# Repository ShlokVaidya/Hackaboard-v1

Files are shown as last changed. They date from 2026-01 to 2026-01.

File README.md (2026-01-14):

# 🎹 Hackaboard - The Hackaboard Keyboard

Welcome to **Hackaboard**, a beautifully crafted **63% mechanical keyboard** that combines aesthetics, functionality, and a touch of personality. A versatile keyboard designed to elevate your typing experience.

---

## ✨ What is Hackaboard?

Hackaboard is a custom mechanical keyboard featuring a 63% layout with modern conveniences like an **OLED display**, **rotary encoder**, and **full programmability**. Whether you're a developer, writer, designer, or gamer, this keyboard adapts to your workflow with support for multiple keymap configurations.

---

## 📸 Gallery

Take a look at the Hackaboard in all its glory:

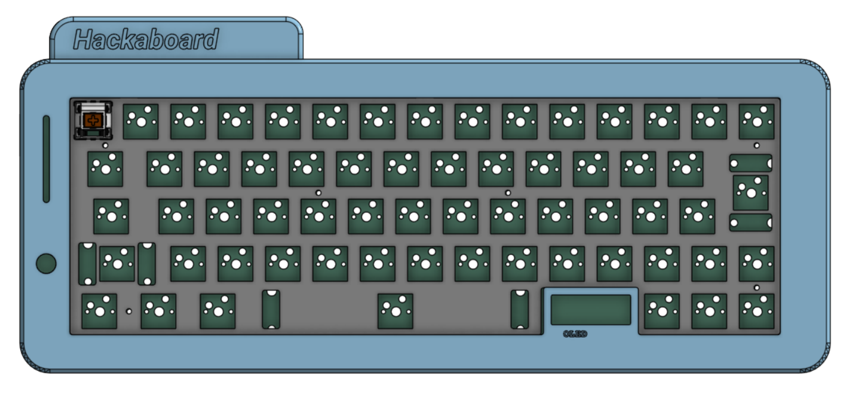
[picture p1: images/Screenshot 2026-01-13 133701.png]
Hackaboard Overview 1


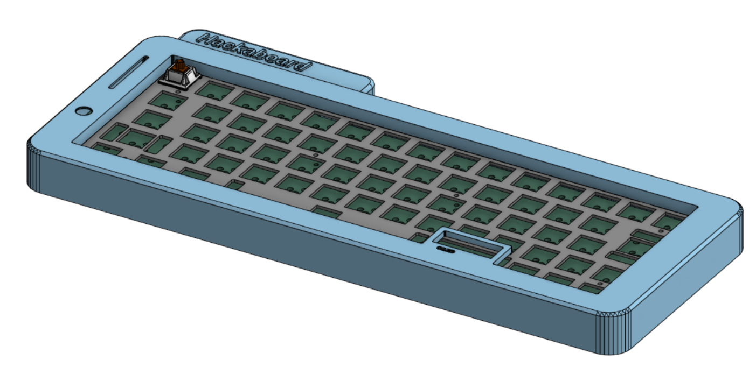
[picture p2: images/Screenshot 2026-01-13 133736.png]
Hackaboard Overview 2


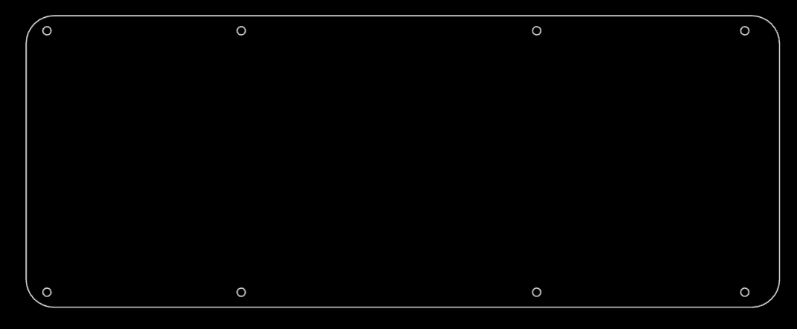
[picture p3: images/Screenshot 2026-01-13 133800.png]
Hackaboard Overview 3


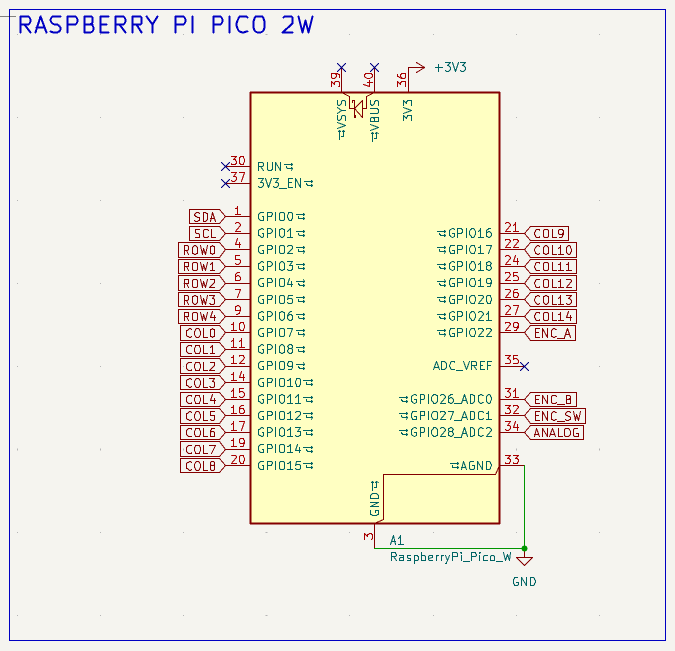
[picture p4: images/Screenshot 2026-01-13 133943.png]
Hackaboard Overview 4


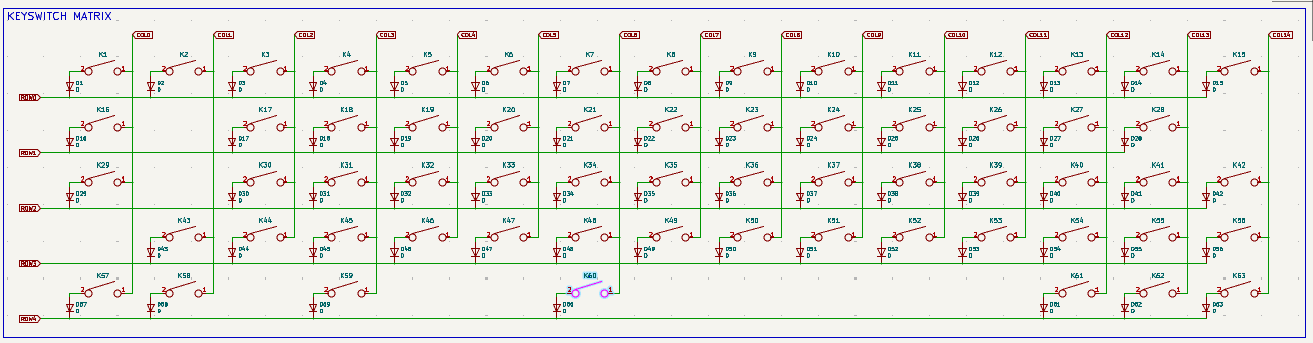
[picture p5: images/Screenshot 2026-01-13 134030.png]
Hackaboard Overview 5


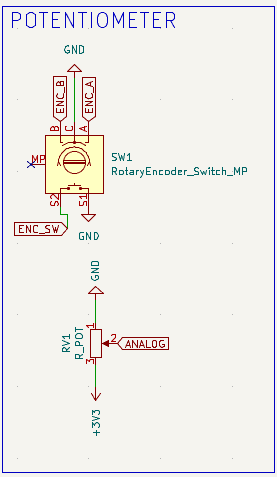
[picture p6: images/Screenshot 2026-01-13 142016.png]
Hackaboard Overview 6


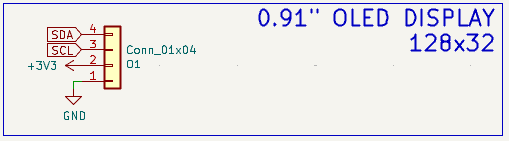
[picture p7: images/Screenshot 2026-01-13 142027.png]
Hackaboard Overview 7


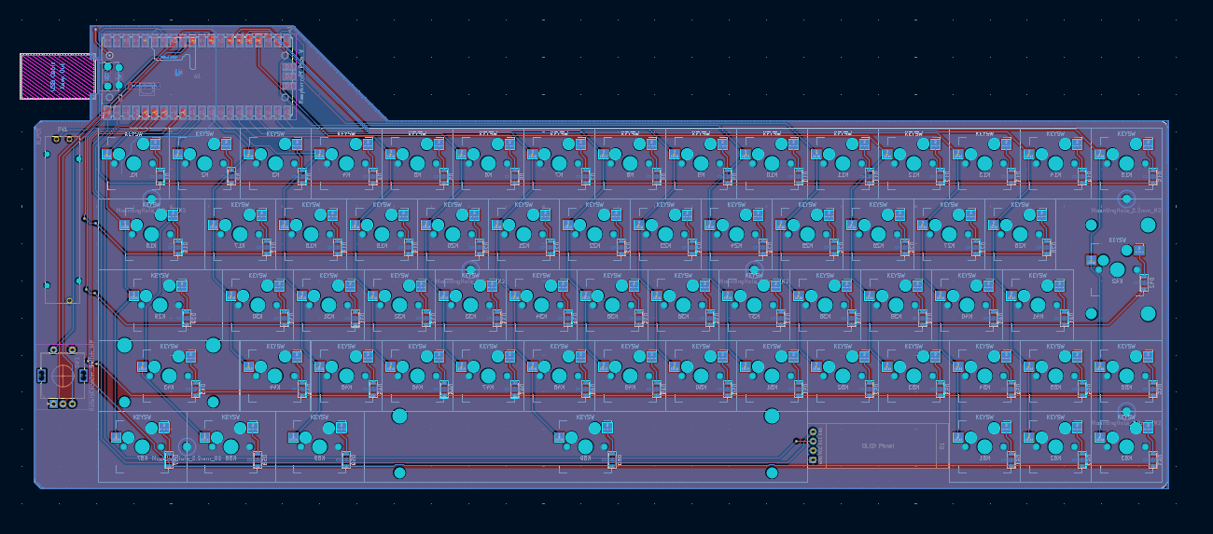
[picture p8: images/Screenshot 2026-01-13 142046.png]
Hackaboard Overview 8


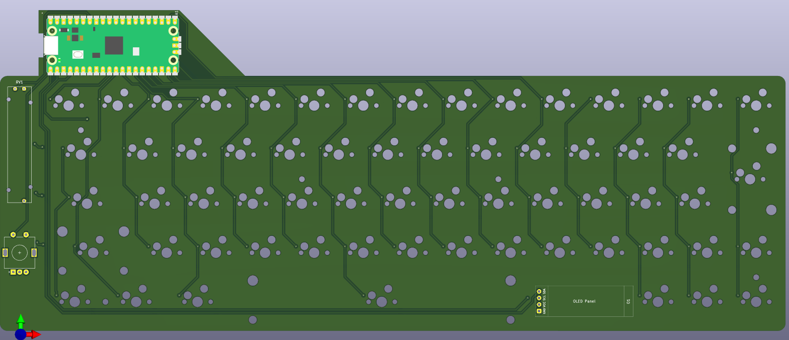
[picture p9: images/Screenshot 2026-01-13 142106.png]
Hackaboard Overview 9


---

## 🎯 Key Features

### Hardware Specs
- **Layout:** 63% compact form factor (63 keys)
- **Microcontroller:** Raspberry Pi Pico 2W (RP2350, supports QMK firmware)
- **Matrix:** 5 rows × 15 columns (COL2ROW configuration)
- **Switch Type:** Cherry MX PCB hotswap compatible
- **Display:** SSD1306 0.91" OLED (128x32 pixels)
- **Input:** EC11 Rotary Encoder with knob support
- **Debounce:** 5ms for reliable key registration

### Software Capabilities
- **Firmware:** QMK-compatible with custom configuration
- **Encoder:** Customizable rotary encoder with 4-level resolution
- **MIDI Support:** Full MIDI protocol implementation for music applications
- **Macros:** Built-in email address macro with right shift + 2
- **Keymaps:** Multiple pre-configured layouts (see below)

Please read [the Journal](./hackaboard-journal.md)
---

## ⌨️ Keymap Configurations

Hackaboard comes with **4 pre-built keymaps** to suit different typing styles and use cases:

### 1. **Default Keymap**
The standard ANSI layout – perfect for everyday typing and programming.

### 2. **Photographer Keymap**
Optimized for photo editing workflows with custom shortcuts and macro assignments.

### 3. **Writer Keymap**
Specialized layout for content creators with quick-access keys for common writing functions.

### 4. **VIA-Compatible Keymap**
Full support for the VIA configurator, allowing you to reprogram your keyboard without touching code.

---

# BOM table

Category | Item | Website | Cost (INR) | Cost (USD)
-- | -- | -- | -- | --
MCU | Raspberry Pi Pico 2 | Robu.in | ₹544 | $6
Diodes | 1N4148 SOD-123 (×63) | Robu.in | ₹36 | $0.4
Shipping (MCU + diodes) | — | Robu.in | ₹49 | $0.54
Subtotal (MCU + diodes) |   |   | ₹630 | $7
Conversion fee (3%) |   |   | ₹650 | $7.22
MCU + Diodes Total |   |   | ₹650 | $7.22
PCB | 2-layer PCB (base settings, incl. GST + shipping) | LionCircuits | ₹5,281 | $58.68
Conversion fee (3%) |   |   | ₹159 | $1.77
PCB Total |   |   | ₹5,440 | $60.45
Switches + Stabilizers + Hotswap sockets | (x45 + x10 pack) | StacksKB | ₹3,604 | $40.04
Conversion fee (3%) |   |   | ₹108 | $1.20
Switches Total |   |   | ₹3,712 | $41.24
Keycaps | Full keycap set | CuriosityCaps | ₹1,999 | $22.21
Conversion fee (3%) |   |   | ₹59 | $0.66
Keycaps Total |   |   | ₹2,058 | $22.87
Non-metal Plate | Plate | robu.in | Rs 330 | 3.6 USD
Screws | | onlyscrews.in | Rs 400 | 4.5 USD
0.91" OLED | | I have
Potentiometer | | I have

And i need 3d printing from #printing-legion so that's Rs 820 or **9 USD**.

## Total
Currency | Total
-- | --
INR | ₹13,400
USD | $147.25 

---

## 🛠️ File Structure

```
Hackaboard-v1/
├── keyboards/hackaboard/         # Main keyboard configuration
│   ├── config.h                  # Hardware configuration
│   ├── info.json                 # Layout and metadata
│   ├── hackaboard.c              # Firmware logic
│   ├── hackaboard.h              # Firmware headers
│   ├── rules.mk                  # Build rules
│   └── keymaps/                  # Keymap definitions
│       ├── default/              # Default layout
│       ├── photographer/         # Photo editing optimized
│       ├── writer/               # Content creation optimized
│       └── via/                  # VIA configurator support
├── PCB/                          # KiCAD PCB design files
│   ├── hackaboard.kicad_sch      # Schematic
│   ├── hackaboard.kicad_pcb      # PCB layout
│   └── production/               # Manufacturing files (BOM, positions)
├── CAD/                          # 3D models and mechanical design
│   ├── case/                     # Keyboard case designs
│   └── plate/                    # Stabilizer plate designs
└── images/                       # Product photography
```

---

## 🚀 Getting Started

### Prerequisites
- QMK Firmware environment set up ([QMK Docs](https://docs.qmk.fm/))
- Python 3.6+ and pip
- ARM GCC toolchain (for RP2350)

### Building the Firmware

1. **Clone the QMK repository** and copy the Hackaboard firmware:
   ```bash
   git clone https://github.com/qmk/qmk_firmware.git
   cp -r keyboards/hackaboard/ qmk_firmware/keyboards/
   ```

2. **Build your preferred keymap:**
   ```bash
   qmk compile -kb hackaboard -km default
   ```

3. **Flash to your keyboard:**
   ```bash
   qmk flash -kb hackaboard -km default
   ```

### VIA Support
If you prefer a graphical interface, use the **VIA configurator**:
1. Download [VIA](https://www.caniusevia.com/)
2. Load the VIA keymap onto your Hackaboard
3. Customize in real-time without reflashing

---

## 🎨 Customization

### Rotary Encoder
The EC11 encoder on Hackaboard can be customized for:
- Volume control
- Scroll wheel simulation
- Layer switching
- Application shortcuts

### OLED Display
The tiny 0.91" OLED shows:
- Current layer information
- Keyboard status
- Custom animations
- Typing statistics

### Email Macro
Quickly insert your email address:
- **Key Combo:** Right Shift + 2
- **Default:** `shlokvaidya.in@gmail.com.com` (customize in `config.h`)

---

## 🔧 Advanced Features

### MIDI Mode
Hackaboard supports MIDI communication for:
- Virtual instrument control
- DAW integration
- Music production workflows

### Debounce Tuning
Adjust key sensitivity without reflashing:
- Current debounce: 5ms
- Modify `DEBOUNCE` in `config.h` if needed

### Custom Firmware Logic
Edit `hackaboard.c` and `hackaboard.h` to add:
- Complex macros
- Display animations
- Sensor integrations
- Hardware customizations

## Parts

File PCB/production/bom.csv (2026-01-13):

Designator | Footprint | Quantity | Value | LCSC Part #
A1 | RaspberryPi_Pico_SMD_HandSolder | 1 | RaspberryPi_Pico_W
D1, D10, D11, D12, D13, D14, D15, D16, D17, D18, D19, D2, D20, D21, D22, D23, D24, D25, D26, D27, D28, D29, D3, D30, D31, D32, D33, D34, D35, D36, D37, D38, D39, D4, D40, D41, D42, D43, D44, D45, D46, D47, D48, D49, D5, D50, D51, D52, D53, D54, D55, D56, D57, D58, D59, D6, D60, D61, D62, D63, D7, D8, D9 | D_SOD-123 | 63 | D
K1, K10, K11, K12, K13, K14, K15, K17, K18, K19, K2, K20, K21, K22, K23, K24, K25, K26, K27, K28, K3, K30, K31, K32, K33, K34, K35, K36, K37, K38, K39, K4, K40, K41, K44, K45, K46, K47, K48, K49, K5, K50, K51, K52, K53, K54, K55, K56, K6, K61, K62, K63, K7, K8, K9 | MXOnly-1U-Hotswap | 55 | KEYSW
K16 | MXOnly-1.5U-Hotswap | 1 | KEYSW
K29 | MXOnly-1.75U-Hotswap | 1 | KEYSW
K42 | MXOnly-ISO-Hotswap | 1 | KEYSW
K43 | MXOnly-2U-Hotswap-ReversedStabilizers | 1 | KEYSW
K57, K58, K59 | MXOnly-1.25U-Hotswap | 3 | KEYSW
K60 | MXOnly-6.25U-Hotswap-ReversedStabilizers | 1 | KEYSW
O1 | SSD1306-0.91-OLED-4pin-128x32 | 1 | Conn_01x04
RV1 | potentiometer_slider_45mm | 1 | R_POT
SW1 | RotaryEncoder_Alps_EC11E-Switch_Vertical_H20mm | 1 | RotaryEncoder_Switch_MP

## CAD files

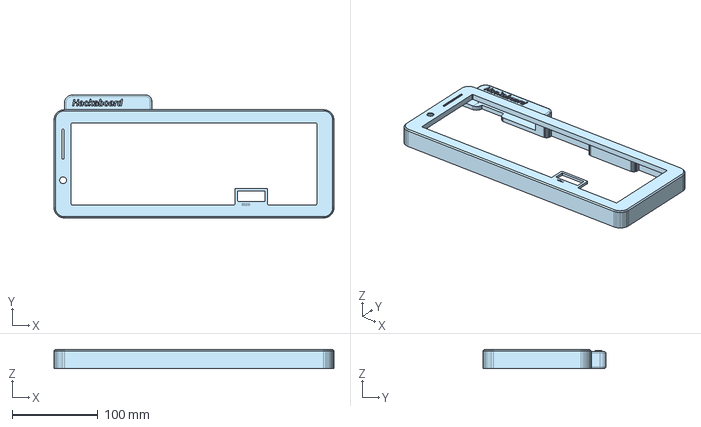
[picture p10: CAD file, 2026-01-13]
CAD/case/case.step
325.8 x 143.0 x 22.4 mm

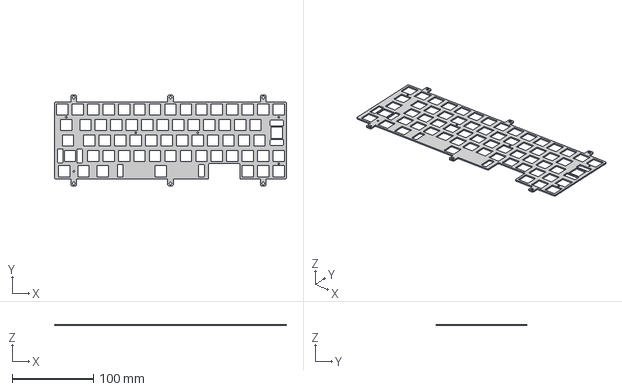
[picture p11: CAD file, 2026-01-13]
CAD/plate/Plate.step
285.7 x 111.8 x 1.50 mm

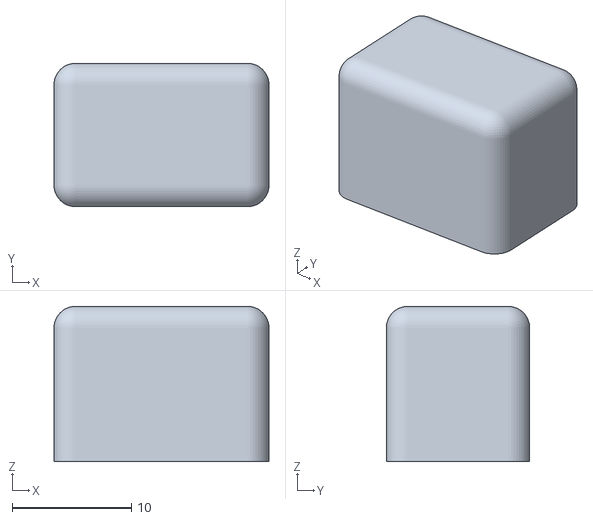
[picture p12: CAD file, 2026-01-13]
CAD/slider cap/slide cap.stl
18.0 x 12.0 x 13.0

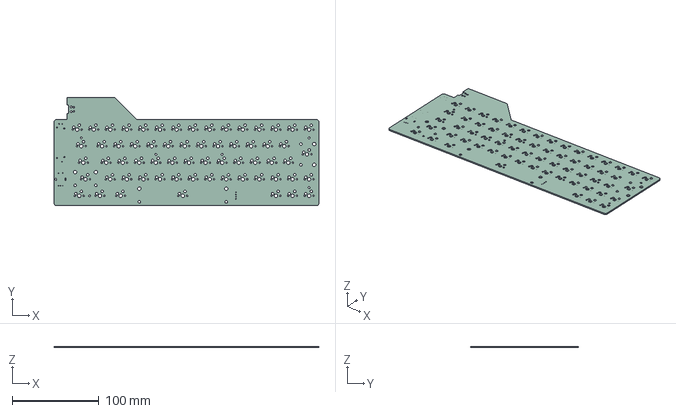
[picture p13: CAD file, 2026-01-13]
CAD/case/hackaboard.step
304.7 x 124.5 x 1.51 mm

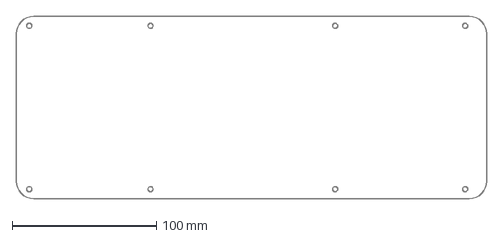
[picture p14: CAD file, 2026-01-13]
CAD/case/buttom_plate.dxf
325.7 x 126.0 mm

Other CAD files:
CAD/plate/plate.dxf

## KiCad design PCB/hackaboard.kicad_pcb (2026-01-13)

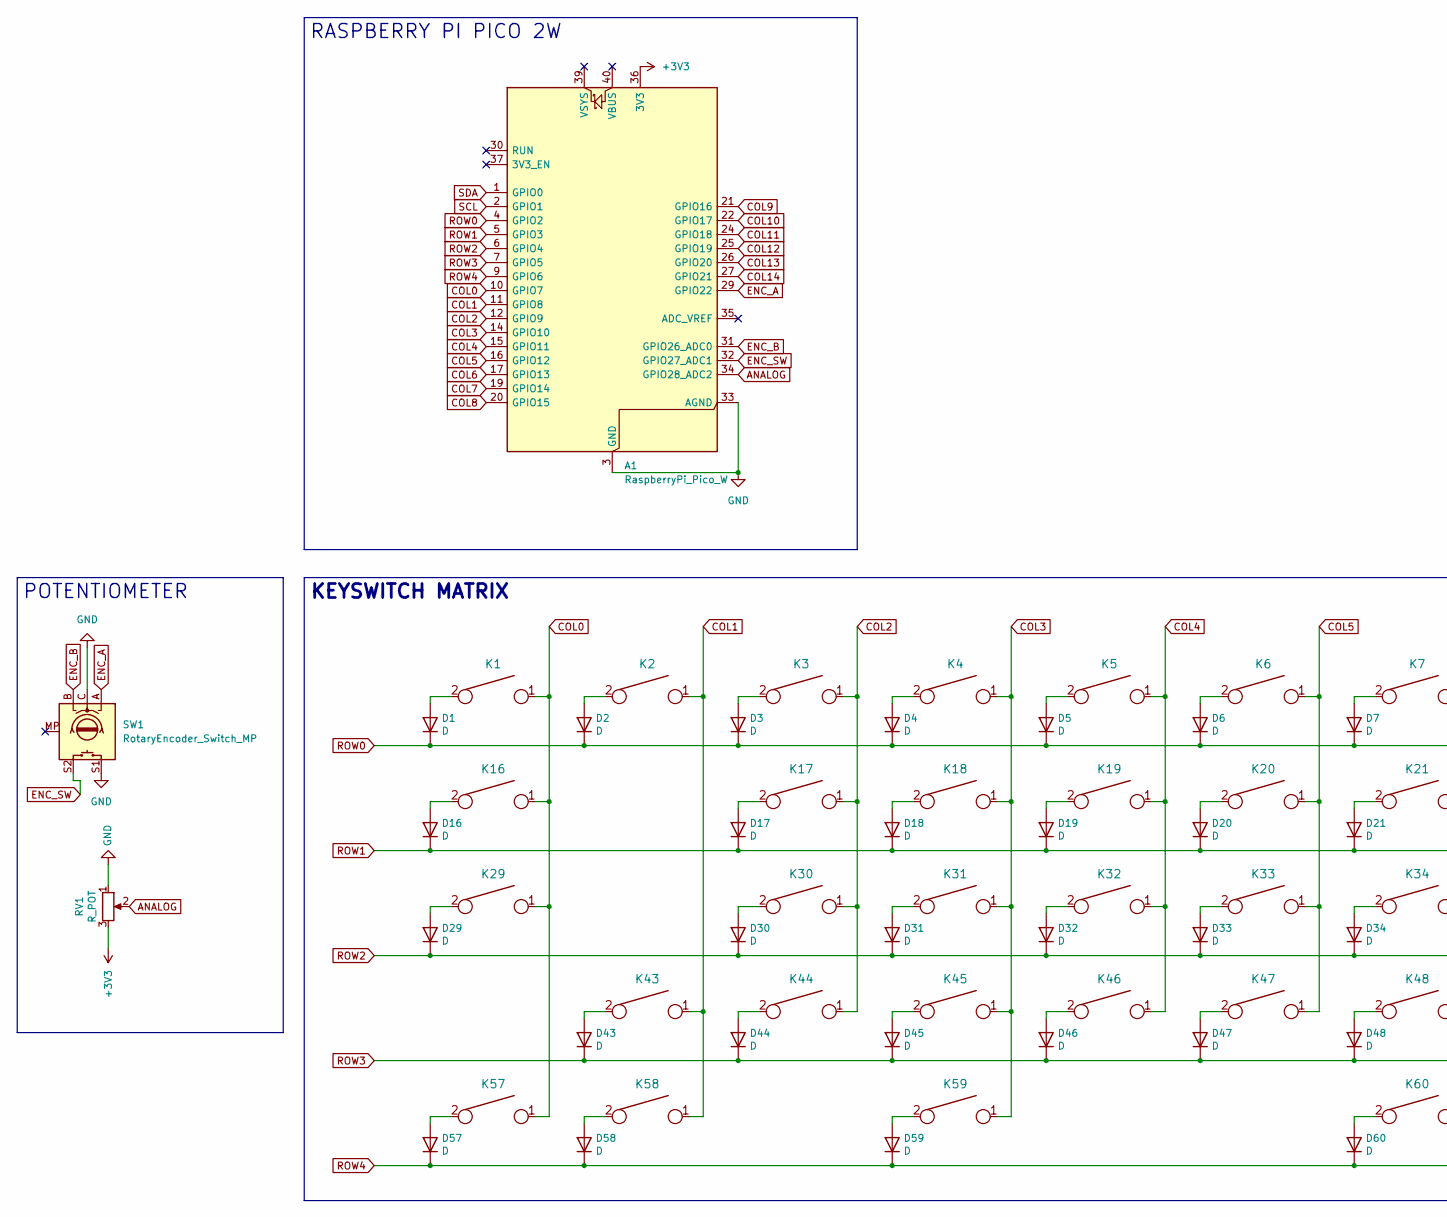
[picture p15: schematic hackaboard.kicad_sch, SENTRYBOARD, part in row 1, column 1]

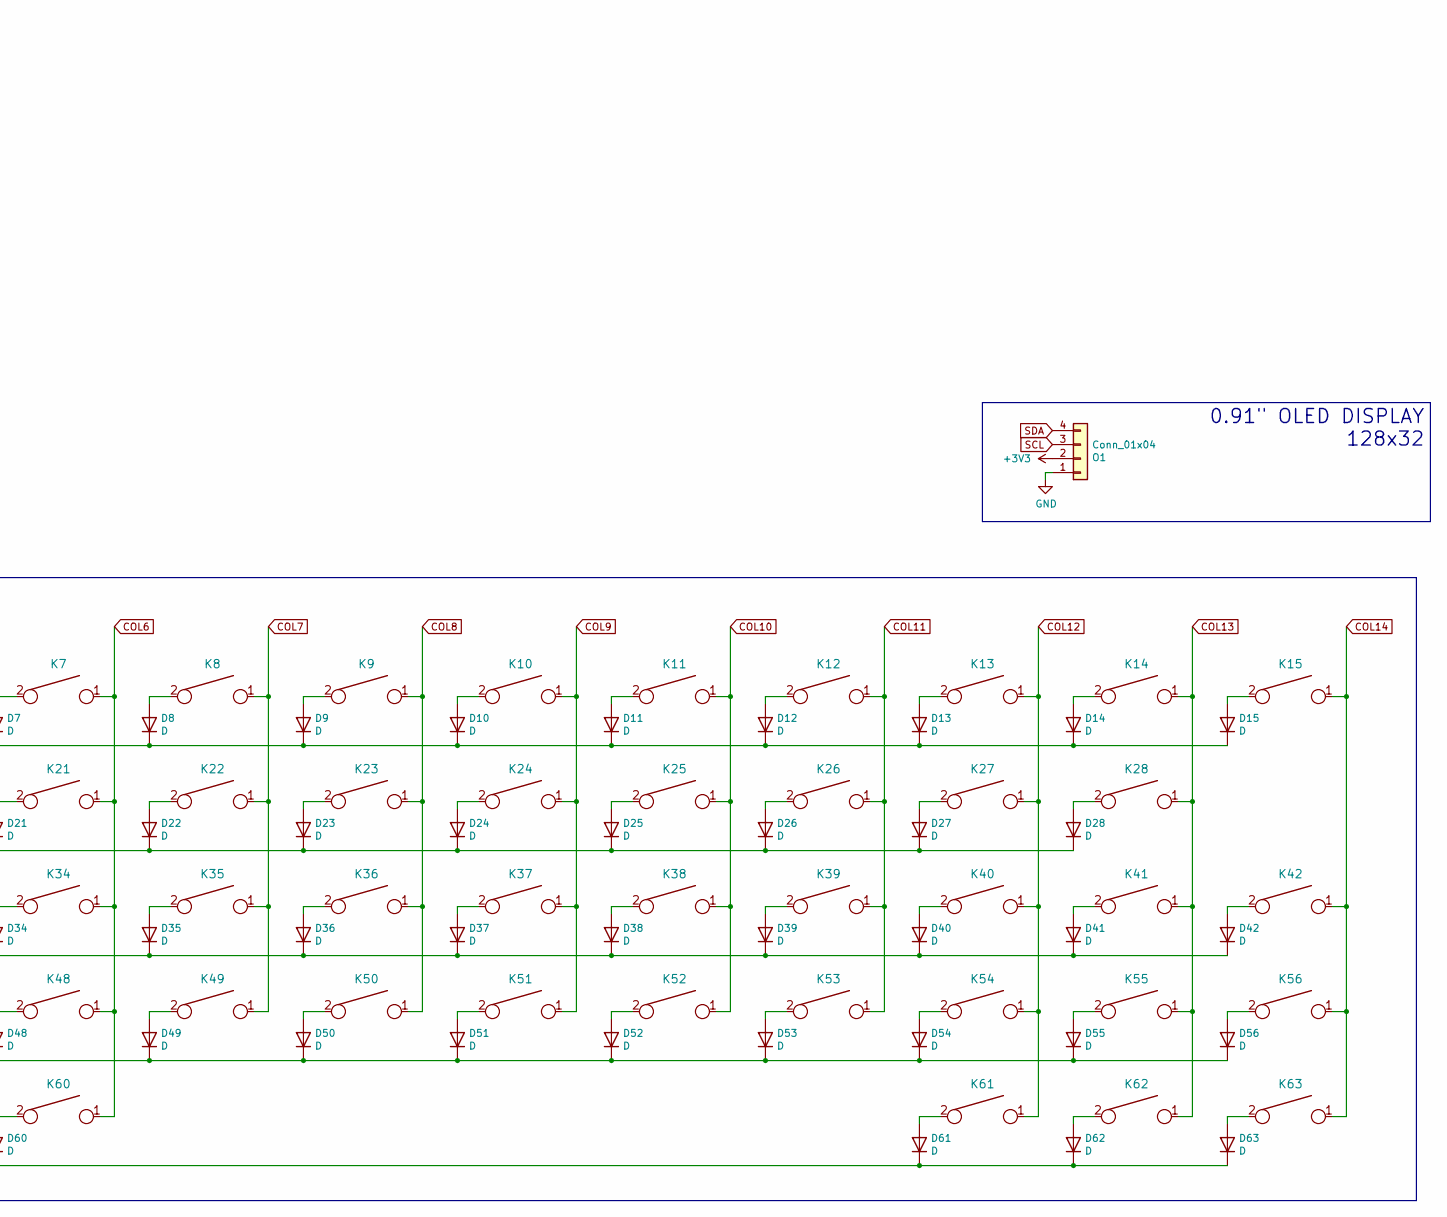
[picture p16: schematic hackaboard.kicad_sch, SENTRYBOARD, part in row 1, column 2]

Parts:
A1: RaspberryPi_Pico_W; RaspberryPi_Pico_SMD_HandSolder
D1, D2, D3, D4, D5, D6, D7, D8, D9, D10, D11, D12, D13, D14, D15, D16, D17, D18, D19, D20, D21, D22, D23, D24, D25, D26, D27, D28, D29, D30, D31, D32, D33, D34, D35, D36, D37, D38, D39, D40, D41, D42, D43, D44, D45, D46, D47, D48, D49, D50, D51, D52, D53, D54, D55, D56, D57, D58, D59, D60, D61, D62, D63: D; D_SOD-123
K1, K2, K3, K4, K5, K6, K7, K8, K9, K10, K11, K12, K13, K14, K15, K17, K18, K19, K20, K21, K22, K23, K24, K25, K26, K27, K28, K30, K31, K32, K33, K34, K35, K36, K37, K38, K39, K40, K41, K44, K45, K46, K47, K48, K49, K50, K51, K52, K53, K54, K55, K56, K61, K62, K63: KEYSW; MXOnly-1U-Hotswap
K16: KEYSW; MXOnly-1.5U-Hotswap
K29: KEYSW; MXOnly-1.75U-Hotswap
K42: KEYSW; MXOnly-ISO-Hotswap
K43: KEYSW; MXOnly-2U-Hotswap-ReversedStabilizers
K57, K58, K59: KEYSW; MXOnly-1.25U-Hotswap
K60: KEYSW; MXOnly-6.25U-Hotswap-ReversedStabilizers
O1: Conn_01x04; SSD1306-0.91-OLED-4pin-128x32
RV1: R_POT; potentiometer_slider_45mm
SW1: RotaryEncoder_Switch_MP; RotaryEncoder_Alps_EC11E-Switch_Vertical_H20mm

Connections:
+3V3: A1.36 (3V3), O1.2, RV1.3
ANALOG: A1.34 (GPIO28_ADC2), RV1.2
COL0: A1.10 (GPIO7), K1.1, K16.1, K29.1, K57.1
COL1: A1.11 (GPIO8), K2.1, K43.1, K58.1
COL2: A1.12 (GPIO9), K3.1, K17.1, K30.1, K44.1
COL3: A1.14 (GPIO10), K4.1, K18.1, K31.1, K45.1, K59.1
COL4: A1.15 (GPIO11), K5.1, K19.1, K32.1, K46.1
COL5: A1.16 (GPIO12), K6.1, K20.1, K33.1, K47.1
COL6: A1.17 (GPIO13), K7.1, K21.1, K34.1, K48.1, K60.1
COL7: A1.19 (GPIO14), K8.1, K22.1, K35.1, K49.1
COL8: A1.20 (GPIO15), K9.1, K23.1, K36.1, K50.1
COL9: A1.21 (GPIO16), K10.1, K24.1, K37.1, K51.1
COL10: A1.22 (GPIO17), K11.1, K25.1, K38.1, K52.1
COL11: A1.24 (GPIO18), K12.1, K26.1, K39.1, K53.1
COL12: A1.25 (GPIO19), K13.1, K27.1, K40.1, K54.1, K61.1
COL13: A1.26 (GPIO20), K14.1, K28.1, K41.1, K55.1, K62.1
COL14: A1.27 (GPIO21), K15.1, K42.1, K56.1, K63.1
ENC_A: A1.29 (GPIO22), SW1.A
ENC_B: A1.31 (GPIO26_ADC0), SW1.B
ENC_SW: A1.32 (GPIO27_ADC1), SW1.S2
GND: A1.3 (GND), A1.8 (GND), A1.13 (GND), A1.18 (GND), A1.23 (GND), A1.28 (GND), A1.33 (AGND), A1.38 (GND), O1.1, RV1.1, SW1.C, SW1.S1
unnamed: D1.2 (A), K1.2
unnamed: D2.2 (A), K2.2
unnamed: D3.2 (A), K3.2
unnamed: D4.2 (A), K4.2
unnamed: D5.2 (A), K5.2
unnamed: D6.2 (A), K6.2
unnamed: D7.2 (A), K7.2
unnamed: D8.2 (A), K8.2
unnamed: D9.2 (A), K9.2
unnamed: D10.2 (A), K10.2
unnamed: D11.2 (A), K11.2
unnamed: D12.2 (A), K12.2
unnamed: D13.2 (A), K13.2
unnamed: D14.2 (A), K14.2
unnamed: D15.2 (A), K15.2
unnamed: D16.2 (A), K16.2
unnamed: D17.2 (A), K17.2
unnamed: D18.2 (A), K18.2
unnamed: D19.2 (A), K19.2
unnamed: D20.2 (A), K20.2
unnamed: D21.2 (A), K21.2
unnamed: D22.2 (A), K22.2
unnamed: D23.2 (A), K23.2
unnamed: D24.2 (A), K24.2
unnamed: D25.2 (A), K25.2
unnamed: D26.2 (A), K26.2
unnamed: D27.2 (A), K27.2
unnamed: D28.2 (A), K28.2
unnamed: D29.2 (A), K29.2
unnamed: D30.2 (A), K30.2
unnamed: D31.2 (A), K31.2
unnamed: D32.2 (A), K32.2
unnamed: D33.2 (A), K33.2
unnamed: D34.2 (A), K34.2
unnamed: D35.2 (A), K35.2
unnamed: D36.2 (A), K36.2
unnamed: D37.2 (A), K37.2
unnamed: D38.2 (A), K38.2
unnamed: D39.2 (A), K39.2
unnamed: D40.2 (A), K40.2
unnamed: D41.2 (A), K41.2
unnamed: D42.2 (A), K42.2
unnamed: D43.2 (A), K43.2
unnamed: D44.2 (A), K44.2
unnamed: D45.2 (A), K45.2
unnamed: D46.2 (A), K46.2
unnamed: D47.2 (A), K47.2
unnamed: D48.2 (A), K48.2
unnamed: D49.2 (A), K49.2
unnamed: D50.2 (A), K50.2
unnamed: D51.2 (A), K51.2
unnamed: D52.2 (A), K52.2
unnamed: D53.2 (A), K53.2
unnamed: D54.2 (A), K54.2
unnamed: D55.2 (A), K55.2
unnamed: D56.2 (A), K56.2
unnamed: D57.2 (A), K57.2
unnamed: D58.2 (A), K58.2
unnamed: D59.2 (A), K59.2
unnamed: D60.2 (A), K60.2
unnamed: D61.2 (A), K61.2
unnamed: D62.2 (A), K62.2
unnamed: D63.2 (A), K63.2
ROW0: A1.4 (GPIO2), D1.1 (K), D2.1 (K), D3.1 (K), D4.1 (K), D5.1 (K), D6.1 (K), D7.1 (K), D8.1 (K), D9.1 (K), D10.1 (K), D11.1 (K), D12.1 (K), D13.1 (K), D14.1 (K), D15.1 (K)
ROW1: A1.5 (GPIO3), D16.1 (K), D17.1 (K), D18.1 (K), D19.1 (K), D20.1 (K), D21.1 (K), D22.1 (K), D23.1 (K), D24.1 (K), D25.1 (K), D26.1 (K), D27.1 (K), D28.1 (K)
ROW2: A1.6 (GPIO4), D29.1 (K), D30.1 (K), D31.1 (K), D32.1 (K), D33.1 (K), D34.1 (K), D35.1 (K), D36.1 (K), D37.1 (K), D38.1 (K), D39.1 (K), D40.1 (K), D41.1 (K), D42.1 (K)
ROW3: A1.7 (GPIO5), D43.1 (K), D44.1 (K), D45.1 (K), D46.1 (K), D47.1 (K), D48.1 (K), D49.1 (K), D50.1 (K), D51.1 (K), D52.1 (K), D53.1 (K), D54.1 (K), D55.1 (K), D56.1 (K)
ROW4: A1.9 (GPIO6), D57.1 (K), D58.1 (K), D59.1 (K), D60.1 (K), D61.1 (K), D62.1 (K), D63.1 (K)
SCL: A1.2 (GPIO1), O1.3
SDA: A1.1 (GPIO0), O1.4

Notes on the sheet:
POTENTIOMETER
RASPBERRY PI PICO 2W
0.91" OLED DISPLAY 128x32
KEYSWITCH MATRIX

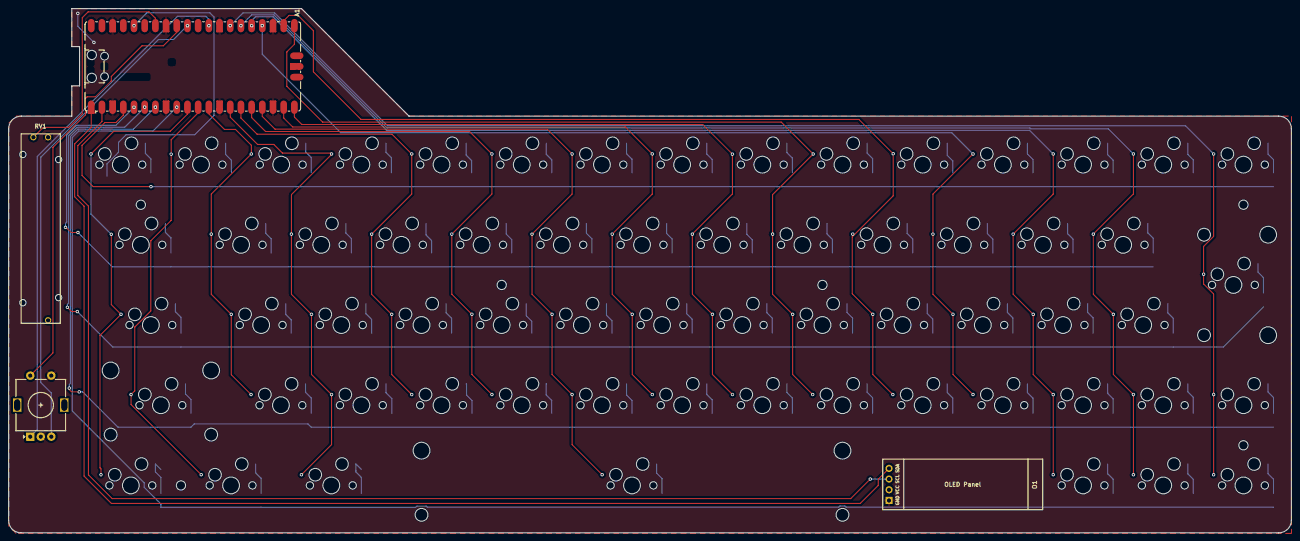
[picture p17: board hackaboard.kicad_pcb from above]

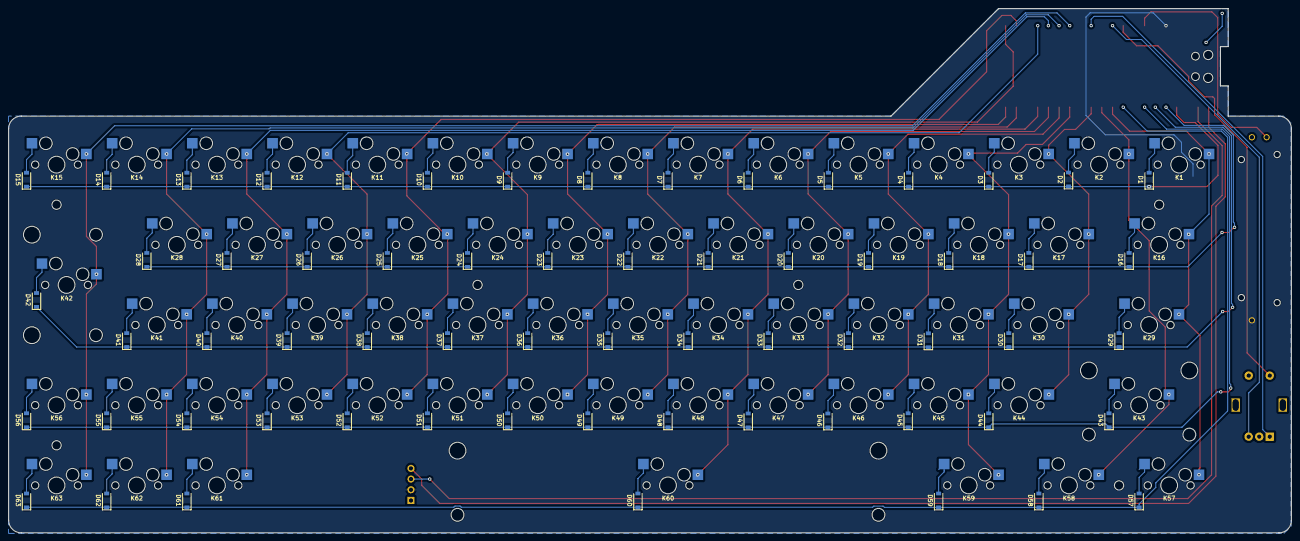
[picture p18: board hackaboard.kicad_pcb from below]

Board: 2 copper layers, 304.7 x 124.5 mm, 136 parts (63 on the bottom side), 91 nets.

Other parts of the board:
[SCREW]: MountingHole_2.2mm_M2
[SCREW]#2, [SCREW]#3, [SCREW]#4, [SCREW]#5, [SCREW]#6: MountingHole_2.2mm_M2

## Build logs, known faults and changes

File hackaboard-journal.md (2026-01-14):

<!--
  This journal is auto generated by Hack Club Blueprint.
-->

## 1/13/2026 6:24 PM - Starting Hackaboard!!!  

_Time spent: 1.0h_  

# Why
I wanted to build a custom mechanical macro keyboard from scratch, not just assemble a kit. The goal was to understand how keyboards actually work at the hardware and firmware level—matrix scanning, diodes, microcontrollers, and firmware like KMK/QMK. I also wanted something practical that I could actually use every day.

# I chose the Pico 2 because:
- It uses the RP2040, which is widely supported in the keyboard community
- It has plenty of GPIO pins for a matrix, encoder.
- Strong documentation and examples exist for CircuitPython and KMK
- It’s powerful enough while still being beginner-friendly.



## 1/13/2026 6:31 PM - Drawing the schematics !  

_Time spent: 1.5h_  

I started by adding all the footprint and symbol library from #hackpad in an sheet. And drew the schematics for the whole hackaboard, this was probably the easiest part. 

# Raspberry Pi Pico 2


# Encoder and 45mm Potentiometer Slider


# The Main Keyboard Matrix


# 0.91" OLED Display


Final after an hour I completed the schematics.
I asked help from #blueprint-help to check if my schematics was right, and err there were a few errors like mismatching wiring of the OLED display and encoder. But after reviewing I fixed all the errors.  

## 1/13/2026 6:35 PM - Routed the PCB  

_Time spent: 3.0h_  

After completing the Schematics headed over to routing the pcb.
This was not so easy more like solving maze problems :cry: . After around 3 hours of changing the design of the board and rerouting and DRC checks, I completed routing the PCB.



## 1/13/2026 6:41 PM - CADDING   

_Time spent: 6.0h_  

Now the most most awaiting part was CADING, tbh i am trash at this, i had to watch a few tutorials before actually starting.

I choose FreeCAD thinking Apps are better than web based apps, and I was wrong, I found even more complicating. I heard that Onshape is most used among Hack Clubbers, so again watch tutorials, and this turned out to be easier and smooth as i dont have a DGPU, am running IGPU :cry:. It took me around two days to design the case, around 6hrs of CADING. As this is my first time so yeah excuses me as i am still learning.

# Final Result 




## 1/13/2026 8 PM - Shoooping  

_Time spent: 2.0h_  

I hate to bring it to you but i tried my best to reduce the cost but its sky rocket high :( pls DM me if you can help me reduce the BOM.

# First of the MCU and 1N4148 SOD-123 Diode :
Raspberry Pi Pico 2 cost around Rs600. And the diodes cost around Rs1/per diode.



Also there's a shipping fee of Rs 49



BTW, I am purchasing from [Robu.in](https://robu.in) and since the grant is in USD i need to pay the conversion that's around 3%. Which comes around **Rs650** or **7.2USD**

# Next is the PCB:
I wanna avoid customs so i choose [Lion Circuit](https://www.lioncircuits.com) with base settings which costs a whooping Rs5281 (incl. Shipping and GST) adding a 3% conversion fee totals up to **Rs5440** which is **60.1 USD**. 



# Key switches, stabilizer and Keycaps:
So the Key switches and stabilizers along with the Hot swap sockets cost Rs3604. 
So i am buying a x45 + x10 pack of Key switches. From [StacksKB](stackskb.com)




For Keycaps i went with [CuriosityCaps](https://curiositycaps.in/)
Rs 1999 with conversion fee its **Rs 2058** or **22 USD**.


# And then for screws i chose from onlyscrews.in which comes around Rs 200 with some shipping charges ( idk during the payout i get the shipping charges probly around 100-300 ) so totals to Rs 400 inc conversion fee ! so around ** 4.5 USD **.

# Plate
I dont if the grant covers this but still putting it
So i need a Polycarbonate 1mm which costs Rs 220 


So totally Rs 330 ( incl of Conversion fee ) or **3.6USD**

# BOM table

Category | Item | Website | Cost (INR) | Cost (USD)
-- | -- | -- | -- | --
MCU | Raspberry Pi Pico 2 | Robu.in | ₹544 | $6
Diodes | 1N4148 SOD-123 (×63) | Robu.in | ₹36 | $0.4
Shipping (MCU + diodes) | — | Robu.in | ₹49 | $0.54
Subtotal (MCU + diodes) |   |   | ₹630 | $7
Conversion fee (3%) |   |   | ₹650 | $7.22
MCU + Diodes Total |   |   | ₹650 | $7.22
PCB | 2-layer PCB (base settings, incl. GST + shipping) | LionCircuits | ₹5,281 | $58.68
Conversion fee (3%) |   |   | ₹159 | $1.77
PCB Total |   |   | ₹5,440 | $60.45
Switches + Stabilizers + Hotswap sockets | (x45 + x10 pack) | StacksKB | ₹3,604 | $40.04
Conversion fee (3%) |   |   | ₹108 | $1.20
Switches Total |   |   | ₹3,712 | $41.24
Keycaps | Full keycap set | CuriosityCaps | ₹1,999 | $22.21
Conversion fee (3%) |   |   | ₹59 | $0.66
Keycaps Total |   |   | ₹2,058 | $22.87
Non-metal Plate | Plate | robu.in | Rs 330 | 3.6 USD
Screws | | onlyscrews.in | Rs 400 | 4.5 USD
0.91" OLED | | I have
Potentiometer | | I have

And i need 3d printing from #printing-legion so that's Rs 820 or **9 USD**.

## Total
Currency | Total
-- | --
INR | ₹13,400
USD | $147.25 

Adding a 3% conversion fee it totals to **Rs 3712** or **41 USD**
`note that i am providing an explanation with proof for the grant, the prices here are hell high, also note that i am in India were aliexpress or any other chinese whole sale retailers are banned, so dont asking me to buy from them. `  

## 1/13/2026 9 PM - Rendering  

_Time spent: 0.1h_  

I have provided all the info required on where the grant is being used, if anything other that required pls DM. I tried to reduce the BOM as much as possible.





Requesting a grant of $150
Tier 2

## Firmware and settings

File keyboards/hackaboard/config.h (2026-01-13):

#pragma once

#include "config_common.h"

/* USB Device descriptor parameter */
#define VENDOR_ID       0xFEED
#define PRODUCT_ID      0x6060
#define DEVICE_VER      0x0001
#define MANUFACTURER    SHLOK
#define PRODUCT         HACKABOARD
#define DESCRIPTION     SEX HACKABOARD

/* key matrix size */
#define MATRIX_ROWS 5
#define MATRIX_COLS 15

/* key matrix pins - GP pins for Raspberry Pi Pico 2W */
#define MATRIX_ROW_PINS { GP2, GP3, GP4, GP5, GP6 }
#define MATRIX_COL_PINS { GP7, GP8, GP9, GP10, GP11, GP12, GP13, GP14, GP15, GP16, GP17, GP18, GP19, GP20, GP21 }

/* I2C pins for OLED on Raspberry Pi Pico 2W */
#define I2C_DRIVER I2CD1
#define I2C1_SDA_PIN GP0
#define I2C1_SCL_PIN GP1

#define OLED_FONT_H "keymaps/default/glcdfont.c"

/* COL2ROW or ROW2COL */
#define DIODE_DIRECTION COL2ROW

/* Set 0 if debouncing isn't needed */
#define DEBOUNCE 5

// #define TAPPING_TERM 200

#define ENCODERS_PAD_A { GP26 }
#define ENCODERS_PAD_B { GP27 }
#define ENCODER_RESOLUTION 4

#define MIDI_BASIC

#define BOOTMAGIC_LITE_ROW 0
#define BOOTMAGIC_LITE_COLUMN 0

#define NO_ACTION_TAPPING
#define NO_ACTION_ONESHOT
#define DISABLE_LEADER

/*enable midi slider*/
// #define POT_ENABLE

/*enable right shift+2 email address marco*/
#define EMAIL_ENABLE
#ifdef EMAIL_ENABLE
	#define EMAIL_ADDRESS "shlok@163.com"
#endif

/*sequence for ctrl, win and alt*/
#define MOD_SEQUENCE_CAW /*normally for macos users*/
// #define MOD_SEQUENCE_CWA /*normally for windows users*/

/*other sequences*/
//#define MOD_SEQUENCE_WAC
//#define MOD_SEQUENCE_WCA
//#define MOD_SEQUENCE_AWC
//#define MOD_SEQUENCE_ACW

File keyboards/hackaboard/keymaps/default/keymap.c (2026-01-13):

#include "hackaboard.h"
#ifdef POT_ENABLE
  #include "analog.h"
#endif
#include "midi.h"

extern MidiDevice midi_device;

#define _BASE 0
#define _FUNC 1
#define _LTRM 2

int16_t pot_oldVal = 0;
int16_t pot_val    = 0;
int16_t pot_ccVal  = 0;
#define POT_TOLERANCE 12

enum { TO_BASE_LAYER_BASE = 0, TO_BASE_LAYER_FUNC, TO_BASE_LAYER_LTRM, /*TO_BASE_LAYER_MIDI*/ };
uint8_t last_stayed_layer = 0;

enum midi_cc_keycodes_LTRM { MIDI_CC1 = SAFE_RANGE, MIDI_CC2, MIDI_CC3, MIDI_CC4, MIDI_CC5, MIDI_CC6, MIDI_CC7, MIDI_CC8, MIDI_CC9, MIDI_CC10, MIDI_CC11, MIDI_CC12, MIDI_CC13, MIDI_CC14, MIDI_CC15, MIDI_CC16, MIDI_CC17, MIDI_CC18, MIDI_CC19, MIDI_CC20, MIDI_CC21, MIDI_CC22, MIDI_CC23, MIDI_CC24, MIDI_CC25, MIDI_CC26 };

static char current_alpha_oled = '\0';
static char current_ltrm_alpha_oled = '\0';

static uint8_t current_MIDI_ccNumber         = 1;
static char    current_MIDI_ccNumber_char[3] = {'0', '1', '\0'};

const uint16_t PROGMEM keymaps[][MATRIX_ROWS][MATRIX_COLS] = {
    [_BASE] = LAYOUT(KC_ESC, KC_1, KC_2, KC_3, KC_4, KC_5, KC_6, KC_7, KC_8, KC_9, KC_0, KC_MINS, KC_EQL, KC_GRV, KC_BSPC,
                     //---
                     KC_TAB, KC_Q, KC_W, KC_E, KC_R, KC_T, KC_Y, KC_U, KC_I, KC_O, KC_P, KC_LBRC, KC_RBRC,
                     //---
                     KC_CAPS, KC_A, KC_S, KC_D, KC_F, KC_G, KC_H, KC_J, KC_K, KC_L, KC_SCLN, KC_QUOT, KC_BSLS, KC_ENT,
                     //---
                     KC_LSFT, KC_Z, KC_X, KC_C, KC_V, KC_B, KC_N, KC_M, KC_COMM, KC_DOT, KC_SLSH, KC_RSFT, KC_UP, TD(TO_BASE_LAYER_BASE),/*TO(_FUNC),*/
                     //---
                     #ifdef MOD_SEQUENCE_CAW
                     KC_LCTL, KC_LALT, KC_LGUI
                     #elif defined(MOD_SEQUENCE_CWA)
                     KC_LCTL, KC_LGUI, KC_LALT
                     #elif defined(MOD_SEQUENCE_WAC)
                     KC_LGUI, KC_LALT, KC_LCTL
                     #elif defined(MOD_SEQUENCE_WCA)
                     KC_LGUI, KC_LCTL, KC_LALT
                     #elif defined(MOD_SEQUENCE_AWC) 
                     KC_LALT, KC_LGUI, KC_LCTL
                     #elif defined(MOD_SEQUENCE_ACW)
                     KC_LALT, KC_LCTL, KC_LGUI
                     #else
                     KC_LCTL, KC_LALT, KC_LGUI
                     #endif
                     , KC_SPC, KC_LEFT, KC_DOWN, KC_RGHT),

    [_FUNC] = LAYOUT(KC_TRNS, KC_F1, KC_F2, KC_F3, KC_F4, KC_F5, KC_F6, KC_F7, KC_F8, KC_F9, KC_F10, KC_TRNS, KC_TRNS, KC_TRNS, KC_TRNS,
                     //-ESC_____1______2______3______4______5______6______7______8______9______10______ _ _______=________`_______bksp
                     KC_TRNS, KC_TRNS, KC_TRNS, KC_TRNS, KC_TRNS, KC_TRNS, KC_TRNS, KC_TRNS, KC_TRNS, KC_TRNS, KC_TRNS, KC_TRNS, KC_TRNS,
                     //-Tab_____q_________w________e________r________t________y________u________i_______o_________p_______{__________}
                     KC_TRNS, KC_TRNS, KC_TRNS, KC_TRNS, KC_TRNS, KC_TRNS, KC_TRNS, KC_TRNS, KC_TRNS, KC_TRNS, KC_TRNS, KC_TRNS, KC_TRNS, KC_TRNS,
                     //-Caps____a_________s________d________f________g________h_______j________k_________l________;________'________\______Enter
                     KC_TRNS, KC_TRNS, KC_TRNS, KC_TRNS, KC_TRNS, KC_TRNS, KC_TRNS, KC_TRNS, KC_TRNS, KC_TRNS, KC_TRNS, KC_TRNS, KC_TRNS, TD(TO_BASE_LAYER_FUNC),/* TO(_LTRM),*/
                     //-Shift___z_________x________c________v________b________n_______m________,_________.________/______Shift______Up_____________fn
                     KC_TRNS, KC_TRNS, KC_TRNS, KC_TRNS, KC_MPRV, KC_MSTP, KC_MNXT),
    				 //-Ctrl____Alt_______Win____Space____Left______Down____Right

    [_LTRM] = LAYOUT(KC_TRNS, MI_C, MI_Db, MI_D, MI_Eb, MI_E, MI_F, MI_Gb, MI_G, MI_Ab, MI_A, MI_Bb, MI_B, MI_C_1, KC_TRNS,
                     //-ESC_____1_____2_____3______4______5____6______7______8_____9_____10____ _ ____=______`______bksp
                     KC_TRNS, MIDI_CC1, MIDI_CC2, MIDI_CC3, MIDI_CC4, MIDI_CC5, MIDI_CC6, MIDI_CC7, MIDI_CC8, MIDI_CC9, MIDI_CC10, KC_TRNS, KC_TRNS,
                     //-Tab_____q_________w__________e_________r_________t_________y_________u_________i_________o__________p_________{_______}
                     KC_TRNS, MIDI_CC11, MIDI_CC12, MIDI_CC13, MIDI_CC14, MIDI_CC15, MIDI_CC16, MIDI_CC17, MIDI_CC18, MIDI_CC19, KC_TRNS, KC_TRNS, KC_TRNS, KC_TRNS,
                     //-Caps______a__________s__________d__________f__________g__________h_________j__________k__________l__________;_______'_________\______Enter
                     KC_TRNS, MIDI_CC20, MIDI_CC21, MIDI_CC22, MIDI_CC23, MIDI_CC24, MIDI_CC25, MIDI_CC26, KC_TRNS, KC_TRNS, KC_TRNS, KC_TRNS, MI_Db_1, TD(TO_BASE_LAYER_LTRM),/* TO(_BASE),*/
                     //-Shift_____z_________x___________c__________v__________b_________n___________m_________,________.________/_______Shift_____Up______________fn
                     KC_TRNS, KC_TRNS, KC_TRNS, KC_TRNS, MI_D_2, MI_Eb_2, MI_E_2),
    				 //-Ctrl____Alt_______Win____Space___Left_____Down_____Right

    // [_MIDI] = LAYOUT(KC_TRNS, MI_CH1, MI_CH2, MI_CH3, MI_CH4, MI_CH5, MI_CH6, MI_CH7, MI_CH8, MI_CH9, MI_CH10, MI_OCTD, MI_OCTU, KC_TRNS, KC_TRNS,
    //                  //-ESC_____1_______2_______3_______4_______5________6______7______8________9_______10________ _ ______=________`______bksp
    //                  KC_TRNS, KC_TRNS, KC_TRNS, KC_TRNS, KC_TRNS, KC_TRNS, KC_TRNS, KC_TRNS, KC_TRNS, KC_TRNS, KC_TRNS, KC_TRNS, KC_TRNS,
    //                  //-Tab_____q_________w__________e_________r_________t_________y_________u_________i_________o__________p_________{___________}
    //                  KC_TRNS, KC_TRNS, MI_Db, MI_Eb, KC_TRNS, MI_Gb, MI_Ab, MI_Bb, KC_TRNS, KC_TRNS, KC_TRNS, KC_TRNS, KC_TRNS, KC_TRNS,
    //                  //-Caps_____a_______s_______d______f_______g______h______j_______k________l________;________'________\______Enter
    //                  KC_TRNS, MI_C, MI_D, MI_E, MI_F, MI_G, MI_A, MI_B, KC_TRNS, KC_TRNS, KC_TRNS, KC_TRNS, MI_VELU, TD(TO_BASE_LAYER_MIDI),
    //                  //-Shift___z_____x____c_____v_____b_____n_____m_______,_________._______/______Shift_____Up______________fn
    //                  KC_TRNS, KC_TRNS, KC_TRNS, KC_TRNS, KC_MPRV, MI_VELD, KC_MNXT),
    // 					//-Ctrl____Alt_______Win____Space___Left_____Down_____Right
};

void dance_layer_BASE(qk_tap_dance_state_t *state, void *user_data) {
    if (state->count == 1) {  // TAP ONCE
        layer_on(_FUNC);
    } else {  // TAP TWICE OR MORE
        layer_on(last_stayed_layer);
    }
}

void dance_layer_reset_BASE(qk_tap_dance_state_t *state, void *user_data) { layer_off(_BASE); }

void dance_layer_FUNC(qk_tap_dance_state_t *state, void *user_data) {
    if (state->count == 1) {  // TAP ONCE
        layer_on(_LTRM);
    } else {  // TAP TWICE OR MORE
        layer_on(_BASE);
        last_stayed_layer = _FUNC;
    }
}
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
